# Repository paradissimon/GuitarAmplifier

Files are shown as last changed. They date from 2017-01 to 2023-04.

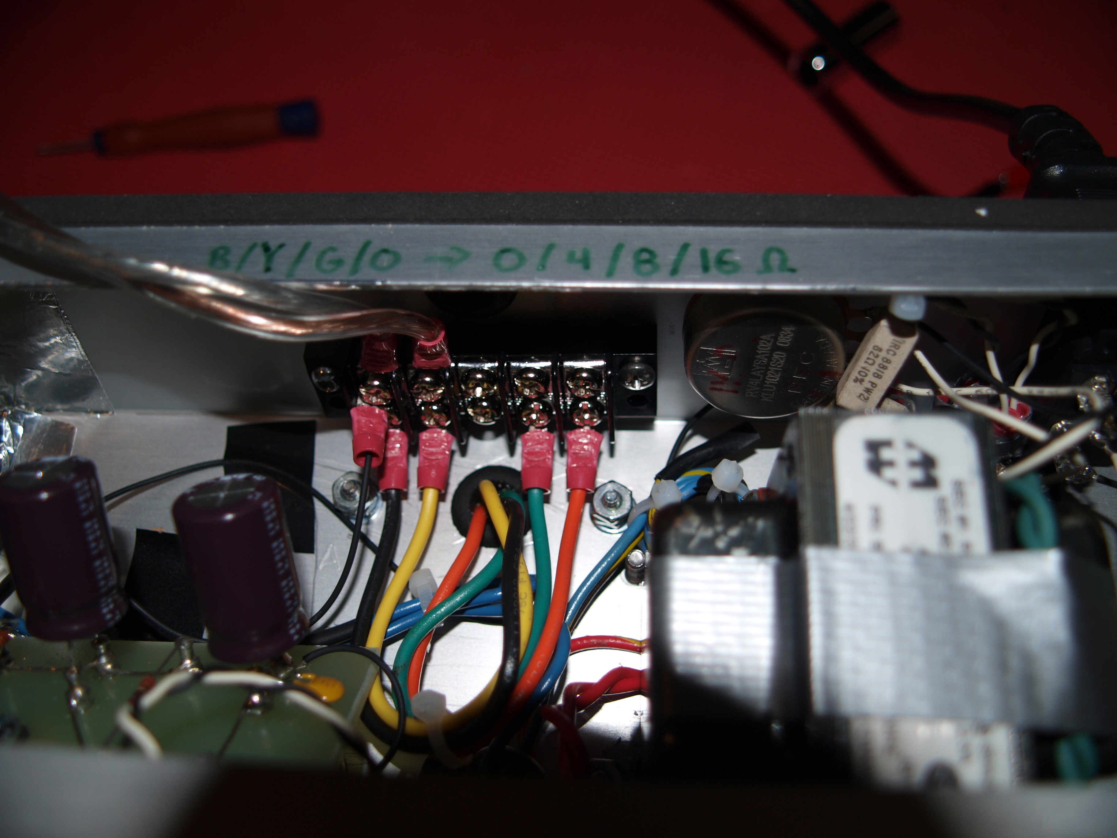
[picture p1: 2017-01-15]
Photos/A0154236.JPG

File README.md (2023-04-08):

All tube class A guitar amplifier
=========================

This is repository contains Autocad DXF layout and LTSpice schematics for a 5W class A guitar amplifier based on a **12AX7** preamplifier tube and **EL84** power tube.

The DXF layout in the Spice folder can be opened with the free QCad software which can be downloaded at http://www.qcad.org/en/qcad-downloads-trial

The schematic file works with Linear Technology's LTSpice electronic simulator available at http://www.linear.com/designtools/software/

The Photo folder contains some pictures of the actual build. I took the aluminium enclosure, cab and speaker out of an existing Line6 Spider III small guitar amplifier. The output transformer is a custom one salvaged from another amplifier. I guess any single-ended 5W/10W output transformer designed for EL84 tubes should be ok; mine has an input impedance of around 6000 ohms. The Line6 speaker is 4 ohms; use proper output tap for other speaker impedances.

Good books related to this project

* [Designing Power Supplies for Valve Amplifiers](https://www.amazon.ca/Designing-Power-Supplies-Valve-Amplifiers/dp/0956154514)

* [Designing Valve Preamps for Guitar and Bass](https://www.amazon.ca/Designing-Valve-Preamps-Guitar-Bass/dp/0956154506)

**Warning! This electronics project contains potentially lethal DC voltages of up to 300 volts.**

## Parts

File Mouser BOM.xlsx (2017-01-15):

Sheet: BOM
Description | # Manufacturier | # Mouser | Qté | Prix | Somme
100R | PR01000101000JR500 | 594-5073NW100R0J | 6 | 0.165 | 0.99 |  | 201.718
120R | PR01000101200JR500 | 594-5073NW120R0J | 6 | 0.165 | 0.99
150R | PR01000101500JR500 | 594-5073NW150R0J | 6 | 0.165 | 0.99
180R | PR01000101800JR500 | 594-5073NW180R0J | 6 | 0.165 | 0.99
220R | PR01000102200JR500 | 594-5073NW220R0J | 6 | 0.165 | 0.99
270R | PR01000102700JR500 | 594-5073NW270R0J | 6 | 0.165 | 0.99
330R | PR01000103300JR500 | 594-5073NW330R0J | 6 | 0.165 | 0.99
390R | PR01000103900JR500 | 594-5073NW390R0J | 6 | 0.165 | 0.99
470R | PR01000104700JR500 | 594-5073NW470R0J | 6 | 0.165 | 0.99
560R | PR01000105600JR500 | 594-5073NW560R0J | 6 | 0.165 | 0.99
680R | PR01000106800JR500 | 594-5073NW680R0J | 6 | 0.165 | 0.99
820R | PR01000108200JR500 | 594-5073NW820R0J | 6 | 0.165 | 0.99
1,0k | PR01000101001JR500 | 594-5073NW1K000J | 6 | 0.165 | 0.99
1,2k | PR01000101201JR500 | 594-5073NW1K200J | 6 | 0.165 | 0.99
1,5k | PR01000101501JR500 | 594-5073NW1K500J | 6 | 0.165 | 0.99
1,8k | PR01000101801JR500 | 594-5073NW1K800J | 6 | 0.165 | 0.99
2,2k | PR01000102201JR500 | 594-5073NW2K200J | 6 | 0.165 | 0.99
2,7k | PR01000102701JR500 | 594-5073NW2K700J | 6 | 0.165 | 0.99
3,3k | PR01000103301JR500 | 594-5073NW3K300J | 6 | 0.165 | 0.99
3,9k | PR01000103901JR500 | 594-5073NW3K900J | 6 | 0.165 | 0.99
4,7k | PR01000104701JR500 | 594-5073NW4K700J | 6 | 0.165 | 0.99
5,6k | PR01000105601JR500 | 594-5073NW5K600J | 6 | 0.165 | 0.99
6,8k | PR01000106801JR500 | 594-5073NW6K800J | 6 | 0.165 | 0.99
8,2k | PR01000108201JR500 | 594-5073NW8K200J | 6 | 0.165 | 0.99
10k | PR01000101002JR500 | 594-5073NW10K00J | 6 | 0.165 | 0.99
12k | PR01000101202JR500 | 594-5073NW12K00J | 6 | 0.165 | 0.99
15k | PR01000101502JR500 | 594-5073NW15K00J | 6 | 0.165 | 0.99
18k | PR01000101802JR500 | 594-5073NW18K00J | 6 | 0.165 | 0.99
22k | PR01000102202JR500 | 594-5073NW22K00J | 6 | 0.165 | 0.99
27k | PR01000102702JR500 | 594-5073NW27K00J | 6 | 0.165 | 0.99
33k | PR01000103302JR500 | 594-5073NW33K00J | 6 | 0.165 | 0.99
39k | PR01000103902JR500 | 594-5073NW39K00J | 6 | 0.165 | 0.99
47k | PR01000104702JR500 | 594-5073NW47K00J | 6 | 0.165 | 0.99
56k | PR01000105602JR500 | 594-5073NW56K00J | 6 | 0.165 | 0.99
68k | PR01000106802JR500 | 594-5073NW68K00J | 6 | 0.165 | 0.99
82k | PR01000108202JR500 | 594-5073NW82K00J | 6 | 0.165 | 0.99
100k | PR01000101003JR500 | 594-5073NW100K0J | 6 | 0.165 | 0.99
120k | PR01000101203JR500 | 594-5073NW120K0J | 6 | 0.165 | 0.99
150k | PR01000101503JR500 | 594-5073NW150K0J | 6 | 0.165 | 0.99
180k | PR01000101803JR500 | 594-5073NW180K0J | 6 | 0.165 | 0.99
220k | PR01000102203JR500 | 594-5073NW220K0J | 6 | 0.165 | 0.99
270k | PR01000102703JR500 | 594-5073NW270K0J | 6 | 0.165 | 0.99
330k | PR01000103303JR500 | 594-5073NW330K0J | 6 | 0.165 | 0.99
390k | PR01000103903JR500 | 594-5073NW390K0J | 6 | 0.165 | 0.99
470k | PR01000104703JR500 | 594-5073NW470K0J | 6 | 0.165 | 0.99
560k | PR01000105603JR500 | 594-5073NW560K0J | 6 | 0.165 | 0.99
680k | PR01000106803JR500 | 594-5073NW680K0J | 6 | 0.165 | 0.99
820k | PR01000108203JR500 | 594-5073NW820K0J | 6 | 0.165 | 0.99
1000k/2W | PR02000201004JR500 | 594-5083NW1M000J | 2 | 0.331 | 0.66
100R / 3W | PR03000201000JAC00 | 594-5093NW100R0J | 4 | 0.475 | 1.90
150R / 3W | PR03000201500JAC00 | 594-5093NW150R0J | 2 | 0.475 | 0.95
180R / 3W | PR03000201800JAC00 | 594-5093NW180R0J | 2 | 0.475 | 0.95
1k / 3W | PR03000201001JAC00 | 594-5093NW1K000J | 2 | 0.475 | 0.95
10k / 3W | PR03000201002JAC00 | 594-5093NW10K00J | 2 | 0.475 | 0.95
4R / 10W | 280-CR10-4.0-RC | 280-CR10-4.0-RC | 2 | 0.661 | 1.32 | Dummy load
UF4007 | UF4007 | 512-UF4007 | 10 | 0.341 | 3.41 | Diode rectification
10uF/50V | UST1C100MDD1TE | 647-UST1C100MDD1TE | 10 | 0.072 | 0.72 | Ref heater
100 uF/16V | UVR1C101MDD1TD | 647-UVR1C101MDD1TD | 10 | 0.052 | 0.52 | Cathode
47uF/350V | UPB2V470MHD | 647-UPB2V470MHD | 4 | 3.320 | 13.28 | Power
Power NPN BJT TO-220F | FJPF5027OTU | 512-FJPF5027OTU | 5 | 0.754 | 3.77
Small signal NPN BJT TO-92 | 2N5551BU | 512-2N5551BU | 50 | 0.039 | 1.95
Power MOSFET | IRF820PBF | 844-IRF820PBF | 5 | 1.210 | 6.05
Zener 12V 1N5242 | 1N5242B-TR | 78-1N5242B | 10 | 0.031 | 0.31 | Protection MOSFET
Ceramic cap 1000V 1nF | H102K25X7RN63J5R | 594-H102K25X7RN63J5R | 25 | 0.062 | 1.55 | Filtering
Film cap 0.0010uF (1.0nF 1000pF) 630V | 150102K630BB | 539-150102K630BB | 2 | 0.475 | 0.95 | Coupling
Film cap 0.0022uF (2.2 nF 2200pF) 630V | 150222J630BB | 539-150222J630BB | 2 | 0.620 | 1.24
Film cap 0.0033uF (3.3 nF 3300pF) 630V | 150332J630BB | 539-150332J630BB | 2 | 0.589 | 1.18
Film cap 0.0047uF (4.7 nF 4700pF) 630V | 150472K630BB | 539-150472K630BB | 2 | 0.527 | 1.05
Film cap 1uF 63V | 150105K63EC | 539-150105K63EC | 1 | 1.020 | 1.02 | Cathode 12ax7
Film cap 0.47uF 100V | 150474K100DC | 539-150474K100DC | 1 | 0.723 | 0.72
Terminal block 2pos | 1546306-2 | 571-15463062 | 1 | 0.527 | 0.53 | AC Mains
Terminal block 3pos | 1546306-3 | 571-15463063 | 2 | 1.000 | 2.00 | Heaters / High voltage
Terminal block 5pos | 1546306-5 | 571-15463065 | 1 | 1.680 | 1.68 | O.T. outputs
Ring terminal 22/20/18 AWG | 19070-0040 | 538-19070-0040 | 35 | 0.196 | 6.86 | Mounts for terminal block
TO220 Insulation kit | 4880SG | 532-4880SG | 2 | 2.100 | 4.20 | Insulation for heatsink
TO220 Heatsink | 577102B04000G | 532-577102B04000G | 2 | 0.393 | 0.79
Wire - Single Conductor 22AWG 7/30 MPPE 100' SPOOL WHITE | 6713 WH005 | 602-6713-100-01 | 1 | 35.850 | 35.85
Wire - Single Conductor 22AWG 7/30 MPPE 100' SPOOL BLACK | 6713 BK005 | 602-6713-100-02 | 1 | 35.850 | 35.85
6.3VAC 3A C.T. Transfor | F16X | 553-F16X | 1 | 12.920 | 12.92
Amber Neon 120V pilot 5/16 hole | 4700A3 | 606-4700A3 | 1 | 1.970 | 1.97
Switch DPST 120V | M2021BB1W01-RO | 633-M2021BB1W01-RO | 1 | 6.150 | 6.15 | Power switch
Order Number: 4468978 (https://ca.mouser.com/OrderHistory/OrderDetail.aspx?qs=9C%2fvjDbyW3X3ZtPHvCQXQaqbB6VQC2yj)

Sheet: Feuil1
 | 594-5073NW100R0J (http://ca.mouser.com/ProductDetail/Vishay-BC-Components/PR01000101000JR500/) | PR01000101000JR500 (http://ca.mouser.com/ProductDetail/Vishay-BC-Components/PR01000101000JR500/) | Vishay/BC Components (http://ca.mouser.com/bccomponents) | Metal Film Resistors - Through Hole 1watt 100ohms 5% PR01 100 5% | Page 727 (http://ca.mouser.com/catalog/catalogCAD/644/727.pdf) | 22.423 | Cut Tape |  |  |  | Details (http://ca.mouser.com/Search/include/RoHSCompliant.aspx?qs=PHIAxeuBAWmYLw3lUtLutA%3d%3d) | 100 Ohms | 5% | 1 Watt | 5073
Enlarge (http://ca.mouser.com/Vishay-BC-Components/Passive-Components/Resistors/Film-Resistors/Metal-Film-Resistors-Through-Hole/_/N-7gz41Z1z13zyf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) |  |  |  |  |  | In Stock | 1:00:00 | $0.165
 |  |  |  |  | Data Sheet |  | 100:00:00 | $0.083 | Min.: | 1
 |  |  |  |  |  |  | 500:00:00 | $0.072 | Mult.: | 1
 |  |  |  |  |  |  | 1,000: | $0.062 | Reel: | 5
 |  |  |  |  |  |  | Reel
 |  |  |  |  |  |  | 5,000: | $0.052
 |  |  |  |  |  |  | 10,000: | View (http://ca.mouser.com/ProductDetail/Vishay-BC-Components/PR01000101000JR500/)
 | 594-5073NW120R0J (http://ca.mouser.com/ProductDetail/Vishay-BC-Components/PR01000101200JR500/) | PR01000101200JR500 (http://ca.mouser.com/ProductDetail/Vishay-BC-Components/PR01000101200JR500/) | Vishay/BC Components (http://ca.mouser.com/bccomponents) | Metal Film Resistors - Through Hole 1watt 120ohms 5% | Page 727 (http://ca.mouser.com/catalog/catalogCAD/644/727.pdf) | 8.745 | Cut Tape |  |  |  | Details (http://ca.mouser.com/Search/include/RoHSCompliant.aspx?qs=PHIAxeuBAWmwXJoypx%252bQGg%3d%3d) | 120 Ohms | 5% | 1 Watt | 5073
Enlarge (http://ca.mouser.com/Vishay-BC-Components/Passive-Components/Resistors/Film-Resistors/Metal-Film-Resistors-Through-Hole/_/N-7gz41Z1z13zyf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) |  |  |  |  |  | In Stock | 1:00:00 | $0.165
 |  |  |  |  | Data Sheet |  | 100:00:00 | $0.083 | Min.: | 1
 |  |  |  |  |  |  | 500:00:00 | $0.072 | Mult.: | 1
 |  |  |  |  |  |  | 1,000: | $0.062 | Reel: | 5
 |  |  |  |  |  |  | Reel
 |  |  |  |  |  |  | 5,000: | $0.052
 |  |  |  |  |  |  | 10,000: | View (http://ca.mouser.com/ProductDetail/Vishay-BC-Components/PR01000101200JR500/)
 | 594-5073NW150R0J (http://ca.mouser.com/ProductDetail/Vishay-BC-Components/PR01000101500JR500/) | PR01000101500JR500 (http://ca.mouser.com/ProductDetail/Vishay-BC-Components/PR01000101500JR500/) | Vishay/BC Components (http://ca.mouser.com/bccomponents) | Metal Film Resistors - Through Hole 1watt 150ohms 5% | Page 727 (http://ca.mouser.com/catalog/catalogCAD/644/727.pdf) | 3.365 | Cut Tape |  |  |  | Details (http://ca.mouser.com/Search/include/RoHSCompliant.aspx?qs=ludH%252bm4YNCMMAySMSlrFlA%3d%3d) | 150 Ohms | 5% | 1 Watt | 5073
Enlarge (http://ca.mouser.com/Vishay-BC-Components/Passive-Components/Resistors/Film-Resistors/Metal-Film-Resistors-Through-Hole/_/N-7gz41Z1z13zyf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) |  |  |  |  |  | In Stock | 1:00:00 | $0.165
 |  |  |  |  | Data Sheet |  | 100:00:00 | $0.083 | Min.: | 1
 |  |  |  |  |  |  | 500:00:00 | $0.072 | Mult.: | 1
 |  |  |  |  |  |  | 1,000: | $0.062 | Reel: | 5
 |  |  |  |  |  |  | Reel
 |  |  |  |  |  |  | 5,000: | $0.052
 |  |  |  |  |  |  | 10,000: | View (http://ca.mouser.com/ProductDetail/Vishay-BC-Components/PR01000101500JR500/)
 | 594-5073NW180R0J (http://ca.mouser.com/ProductDetail/Vishay-BC-Components/PR01000101800JR500/) | PR01000101800JR500 (http://ca.mouser.com/ProductDetail/Vishay-BC-Components/PR01000101800JR500/) | Vishay/BC Components (http://ca.mouser.com/bccomponents) | Metal Film Resistors - Through Hole 1watt 180ohms 5% | Page 727 (http://ca.mouser.com/catalog/catalogCAD/644/727.pdf) | 9.241 | Cut Tape |  |  |  | Details (http://ca.mouser.com/Search/include/RoHSCompliant.aspx?qs=YmUReEAocUl%252bDAZht9mY8A%3d%3d) | 180 Ohms | 5% | 1 Watt | 5073
Enlarge (http://ca.mouser.com/Vishay-BC-Components/Passive-Components/Resistors/Film-Resistors/Metal-Film-Resistors-Through-Hole/_/N-7gz41Z1z13zyf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) |  |  |  |  |  | In Stock | 1:00:00 | $0.165
 |  |  |  |  | Data Sheet |  | 100:00:00 | $0.083 | Min.: | 1
 |  |  |  |  |  |  | 500:00:00 | $0.072 | Mult.: | 1
 |  |  |  |  |  |  | 1,000: | $0.062 | Reel: | 5
 |  |  |  |  |  |  | Reel
 |  |  |  |  |  |  | 5,000: | $0.052
 |  |  |  |  |  |  | 10,000: | View (http://ca.mouser.com/ProductDetail/Vishay-BC-Components/PR01000101800JR500/)
 | 594-5073NW220R0J (http://ca.mouser.com/ProductDetail/Vishay-BC-Components/PR01000102200JR500/) | PR01000102200JR500 (http://ca.mouser.com/ProductDetail/Vishay-BC-Components/PR01000102200JR500/) | Vishay/BC Components (http://ca.mouser.com/bccomponents) | Metal Film Resistors - Through Hole 1watt 220ohms 5% | Page 727 (http://ca.mouser.com/catalog/catalogCAD/644/727.pdf) | 12.401 | Cut Tape |  |  |  | Details (http://ca.mouser.com/Search/include/RoHSCompliant.aspx?qs=MQFOFZiEXaSG%2fquX5pavNw%3d%3d) | 220 Ohms | 5% | 1 Watt | 5073
Enlarge (http://ca.mouser.com/Vishay-BC-Components/Passive-Components/Resistors/Film-Resistors/Metal-Film-Resistors-Through-Hole/_/N-7gz41Z1z13zyf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) |  |  |  |  |  | In Stock | 1:00:00 | $0.165
 |  |  |  |  | Data Sheet |  | 100:00:00 | $0.083 | Min.: | 1
 |  |  |  |  |  |  | 500:00:00 | $0.072 | Mult.: | 1
 |  |  |  |  |  |  | 1,000: | $0.062 | Reel: | 5
 |  |  |  |  |  |  | Reel
 |  |  |  |  |  |  | 5,000: | $0.052
 |  |  |  |  |  |  | 10,000: | View (http://ca.mouser.com/ProductDetail/Vishay-BC-Components/PR01000102200JR500/)
 | 594-5073NW270R0J (http://ca.mouser.com/ProductDetail/Vishay-BC-Components/PR01000102700JR500/) | PR01000102700JR500 (http://ca.mouser.com/ProductDetail/Vishay-BC-Components/PR01000102700JR500/) | Vishay/BC Components (http://ca.mouser.com/bccomponents) | Metal Film Resistors - Through Hole 1watt 270ohms 5% | Page 727 (http://ca.mouser.com/catalog/catalogCAD/644/727.pdf) | 7.003 | Cut Tape |  |  |  | Details (http://ca.mouser.com/Search/include/RoHSCompliant.aspx?qs=14uVlELD1UoBj7tWtgOd9g%3d%3d) | 270 Ohms | 5% | 1 Watt | 5073
Enlarge (http://ca.mouser.com/Vishay-BC-Components/Passive-Components/Resistors/Film-Resistors/Metal-Film-Resistors-Through-Hole/_/N-7gz41Z1z13zyf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) |  |  |  |  |  | In Stock | 1:00:00 | $0.165
 |  |  |  |  | Data Sheet |  | 100:00:00 | $0.083 | Min.: | 1
 |  |  |  |  |  |  | 500:00:00 | $0.072 | Mult.: | 1
 |  |  |  |  |  |  | 1,000: | $0.062 | Reel: | 5
 |  |  |  |  |  |  | Reel
 |  |  |  |  |  |  | 5,000: | $0.052
 |  |  |  |  |  |  | 10,000: | View (http://ca.mouser.com/ProductDetail/Vishay-BC-Components/PR01000102700JR500/)
 | 594-5073NW330R0J (http://ca.mouser.com/ProductDetail/Vishay-BC-Components/PR01000103300JR500/) | PR01000103300JR500 (http://ca.mouser.com/ProductDetail/Vishay-BC-Components/PR01000103300JR500/) | Vishay/BC Components (http://ca.mouser.com/bccomponents) | Metal Film Resistors - Through Hole 1watt 330ohms 5% | Page 727 (http://ca.mouser.com/catalog/catalogCAD/644/727.pdf) | 11.385 | Cut Tape |  |  |  | Details (http://ca.mouser.com/Search/include/RoHSCompliant.aspx?qs=ebpeZUi5yKl%2fG1VsOnD%2fZw%3d%3d) | 330 Ohms | 5% | 1 Watt | 5073
Enlarge (http://ca.mouser.com/Vishay-BC-Components/Passive-Components/Resistors/Film-Resistors/Metal-Film-Resistors-Through-Hole/_/N-7gz41Z1z13zyf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) |  |  |  |  |  | In Stock | 1:00:00 | $0.165
 |  |  |  |  | Data Sheet | More Info Available (http://ca.mouser.com/ProductDetail/Vishay-BC-Components/PR01000103300JR500/) | 100:00:00 | $0.083 | Min.: | 1
 |  |  |  |  |  |  | 500:00:00 | $0.072 | Mult.: | 1
 |  |  |  |  |  |  | 1,000: | $0.062 | Reel: | 5
 |  |  |  |  |  |  | Reel
 |  |  |  |  |  |  | 5,000: | $0.052
 |  |  |  |  |  |  | 10,000: | View (http://ca.mouser.com/ProductDetail/Vishay-BC-Components/PR01000103300JR500/)
 | 594-5073NW390R0J (http://ca.mouser.com/ProductDetail/Vishay-BC-Components/PR01000103900JR500/) | PR01000103900JR500 (http://ca.mouser.com/ProductDetail/Vishay-BC-Components/PR01000103900JR500/) | Vishay/BC Components (http://ca.mouser.com/bccomponents) | Metal Film Resistors - Through Hole 1watt 390ohms 5% | Page 727 (http://ca.mouser.com/catalog/catalogCAD/644/727.pdf) | 8.192 | Cut Tape |  |  |  | Details (http://ca.mouser.com/Search/include/RoHSCompliant.aspx?qs=PHIAxeuBAWklVInDMciCUA%3d%3d) | 390 Ohms | 5% | 1 Watt | 5073
Enlarge (http://ca.mouser.com/Vishay-BC-Components/Passive-Components/Resistors/Film-Resistors/Metal-Film-Resistors-Through-Hole/_/N-7gz41Z1z13zyf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) |  |  |  |  |  | In Stock | 1:00:00 | $0.165
 |  |  |  |  | Data Sheet |  | 100:00:00 | $0.083 | Min.: | 1
 |  |  |  |  |  |  | 500:00:00 | $0.072 | Mult.: | 1
 |  |  |  |  |  |  | 1,000: | $0.062 | Reel: | 5
 |  |  |  |  |  |  | Reel
 |  |  |  |  |  |  | 5,000: | $0.052
 |  |  |  |  |  |  | 10,000: | View (http://ca.mouser.com/ProductDetail/Vishay-BC-Components/PR01000103900JR500/)
 | 594-5073NW470R0J (http://ca.mouser.com/ProductDetail/Vishay-BC-Components/PR01000104700JR500/) | PR01000104700JR500 (http://ca.mouser.com/ProductDetail/Vishay-BC-Components/PR01000104700JR500/) | Vishay/BC Components (http://ca.mouser.com/bccomponents) | Metal Film Resistors - Through Hole 1watt 470ohms 5% | Page 727 (http://ca.mouser.com/catalog/catalogCAD/644/727.pdf) | 16.38 | Cut Tape |  |  |  | Details (http://ca.mouser.com/Search/include/RoHSCompliant.aspx?qs=ChQ8krfRUi61iVVrFGp3Pg%3d%3d) | 470 Ohms | 5% | 1 Watt | PR01
Enlarge (http://ca.mouser.com/Vishay-BC-Components/Passive-Components/Resistors/Film-Resistors/Metal-Film-Resistors-Through-Hole/_/N-7gz41Z1z13zyf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) |  |  |  |  |  | In Stock | 1:00:00 | $0.165
 |  |  |  |  | Data Sheet |  | 100:00:00 | $0.083 | Min.: | 1
 |  |  |  |  |  |  | 500:00:00 | $0.072 | Mult.: | 1
 |  |  |  |  |  |  | 1,000: | $0.062 | Reel: | 5
 |  |  |  |  |  |  | Reel
 |  |  |  |  |  |  | 5,000: | $0.052
 |  |  |  |  |  |  | 10,000: | View (http://ca.mouser.com/ProductDetail/Vishay-BC-Components/PR01000104700JR500/)
 | 594-5073NW560R0J (http://ca.mouser.com/ProductDetail/Vishay-BC-Components/PR01000105600JR500/) | PR01000105600JR500 (http://ca.mouser.com/ProductDetail/Vishay-BC-Components/PR01000105600JR500/) | Vishay/BC Components (http://ca.mouser.com/bccomponents) | Metal Film Resistors - Through Hole 1watt 560ohms 5% | Page 727 (http://ca.mouser.com/catalog/catalogCAD/644/727.pdf) | 7.882 | Cut Tape |  |  |  | Details (http://ca.mouser.com/Search/include/RoHSCompliant.aspx?qs=Zec1518NjxB0xdYBqc311Q%3d%3d) | 560 Ohms | 5% | 1 Watt | 5073
Enlarge (http://ca.mouser.com/Vishay-BC-Components/Passive-Components/Resistors/Film-Resistors/Metal-Film-Resistors-Through-Hole/_/N-7gz41Z1z13zyf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) |  |  |  |  |  | In Stock | 1:00:00 | $0.165
 |  |  |  |  | Data Sheet |  | 100:00:00 | $0.083 | Min.: | 1
 |  |  |  |  |  |  | 500:00:00 | $0.072 | Mult.: | 1
 |  |  |  |  |  |  | 1,000: | $0.062 | Reel: | 5
 |  |  |  |  |  |  | Reel
 |  |  |  |  |  |  | 5,000: | $0.052
 |  |  |  |  |  |  | 10,000: | View (http://ca.mouser.com/ProductDetail/Vishay-BC-Components/PR01000105600JR500/)
 | 594-5073NW680R0J (http://ca.mouser.com/ProductDetail/Vishay-BC-Components/PR01000106800JR500/) | PR01000106800JR500 (http://ca.mouser.com/ProductDetail/Vishay-BC-Components/PR01000106800JR500/) | Vishay/BC Components (http://ca.mouser.com/bccomponents) | Metal Film Resistors - Through Hole 1watt 680ohms 5% | Page 727 (http://ca.mouser.com/catalog/catalogCAD/644/727.pdf) | 6.624 | Cut Tape |  |  |  | Details (http://ca.mouser.com/Search/include/RoHSCompliant.aspx?qs=ludH%252bm4YNCNk6ULJYj2wlw%3d%3d) | 680 Ohms | 5% | 1 Watt | 5073
Enlarge (http://ca.mouser.com/Vishay-BC-Components/Passive-Components/Resistors/Film-Resistors/Metal-Film-Resistors-Through-Hole/_/N-7gz41Z1z13zyf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) |  |  |  |  |  | In Stock | 1:00:00 | $0.165
 |  |  |  |  | Data Sheet |  | 100:00:00 | $0.083 | Min.: | 1
 |  |  |  |  |  |  | 500:00:00 | $0.072 | Mult.: | 1
 |  |  |  |  |  |  | 1,000: | $0.062 | Reel: | 5
 |  |  |  |  |  |  | Reel
 |  |  |  |  |  |  | 5,000: | $0.052
 |  |  |  |  |  |  | 10,000: | View (http://ca.mouser.com/ProductDetail/Vishay-BC-Components/PR01000106800JR500/)
 | 594-5073NW820R0J (http://ca.mouser.com/ProductDetail/Vishay-BC-Components/PR01000108200JR500/) | PR01000108200JR500 (http://ca.mouser.com/ProductDetail/Vishay-BC-Components/PR01000108200JR500/) | Vishay/BC Components (http://ca.mouser.com/bccomponents) | Metal Film Resistors - Through Hole 1watt 820ohms 5% | Page 727 (http://ca.mouser.com/catalog/catalogCAD/644/727.pdf) | 5.778 | Cut Tape |  |  |  | Details (http://ca.mouser.com/Search/include/RoHSCompliant.aspx?qs=ludH%252bm4YNCP1VssKPNJtEw%3d%3d) | 820 Ohms | 5
Enlarge (http://ca.mouser.com/Vishay-BC-Components/Passive-Components/Resistors/Film-Resistors/Metal-Film-Resistors-Through-Hole/_/N-7gz41Z1z13zyf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) |  |  |  |  |  | In Stock | 1:00:00 | $0.165
 |  |  |  |  | Data Sheet |  | 100:00:00 | $0.083 | Min.: | 1
 |  |  |  |  |  |  | 500:00:00 | $0.072 | Mult.: | 1
 |  |  |  |  |  |  | 1,000: | $0.062 | Reel: | 5
 |  |  |  |  |  |  | Reel
 |  |  |  |  |  |  | 5,000: | $0.052
 |  |  |  |  |  |  | 10,000: | View (http://ca.mouser.com/ProductDetail/Vishay-BC-Components/PR01000108200JR500/)

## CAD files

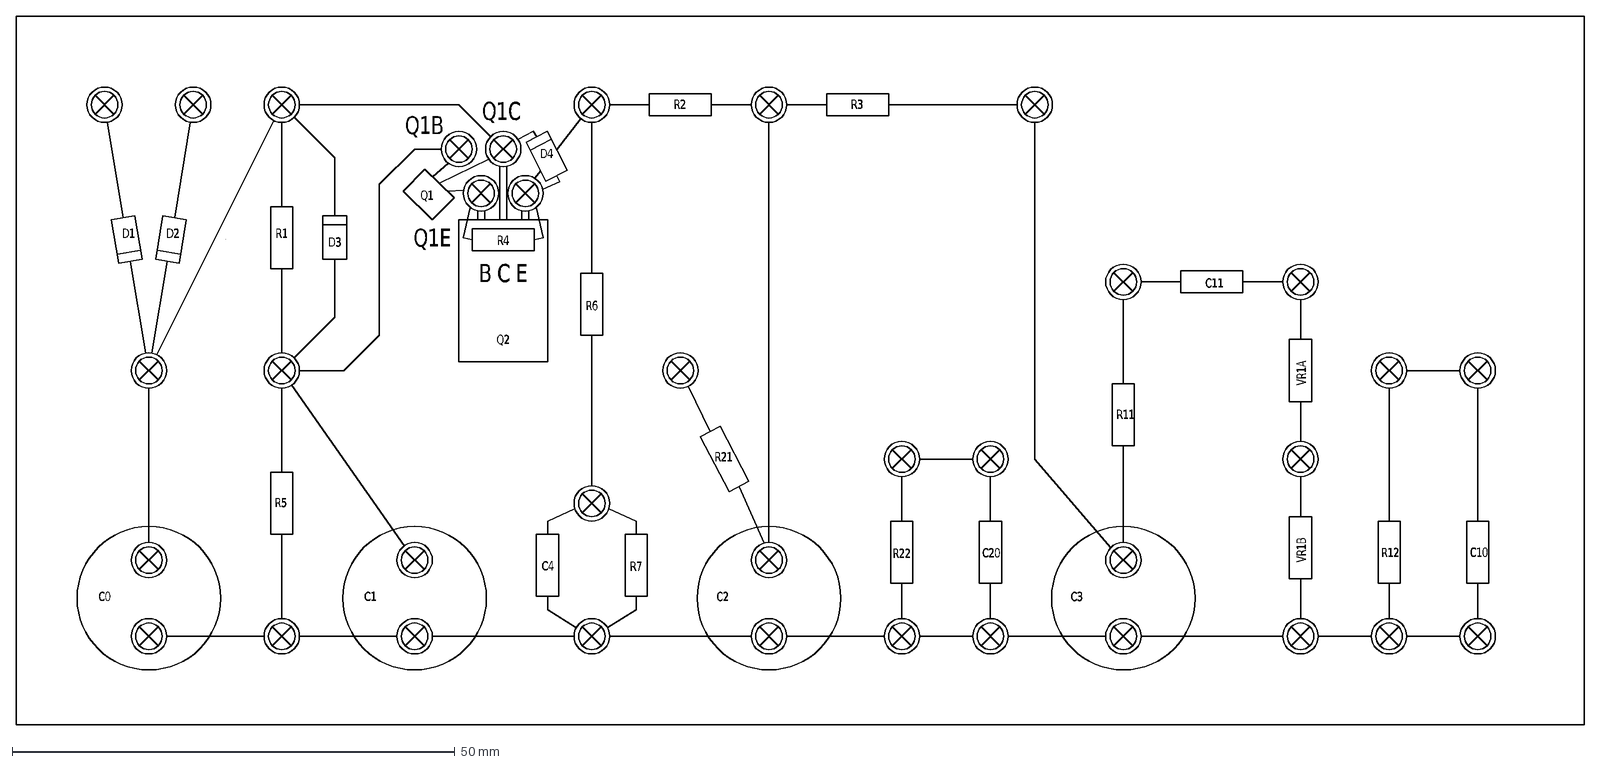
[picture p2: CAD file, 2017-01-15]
Plan/Layout.dxf
D1
D2
D3
R1
R5
C0
C1
Q2
R4
D4
Q1E
Q1B
Q1C
B C E
Q1
R6
C4
R7
C2
R2
R3
R21
C3
R22
C20
R11
VR1A
VR1B
C11
R12
C10

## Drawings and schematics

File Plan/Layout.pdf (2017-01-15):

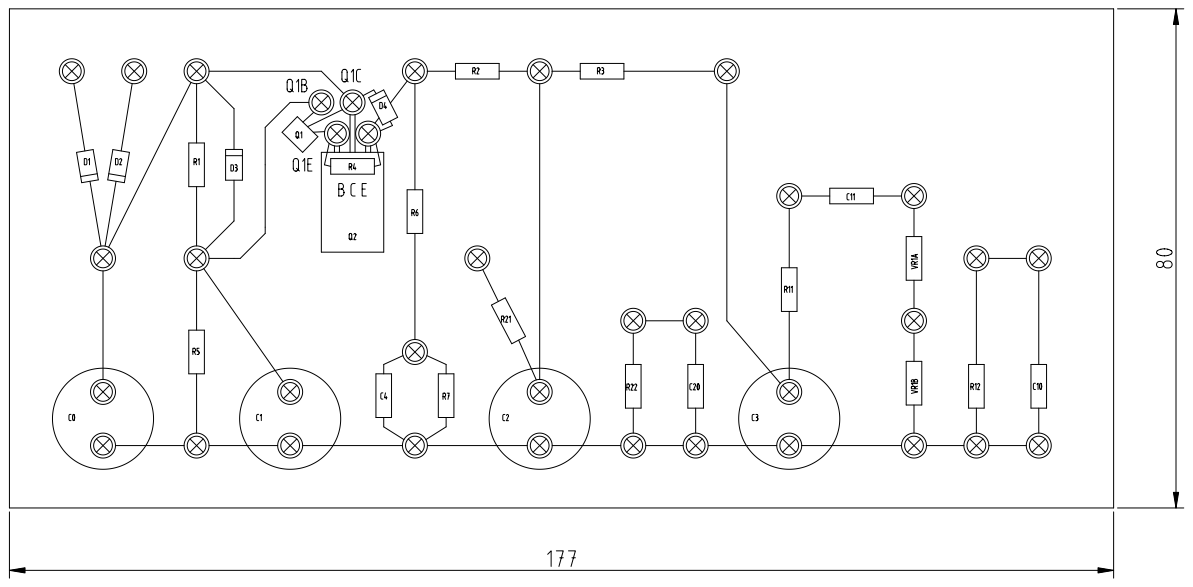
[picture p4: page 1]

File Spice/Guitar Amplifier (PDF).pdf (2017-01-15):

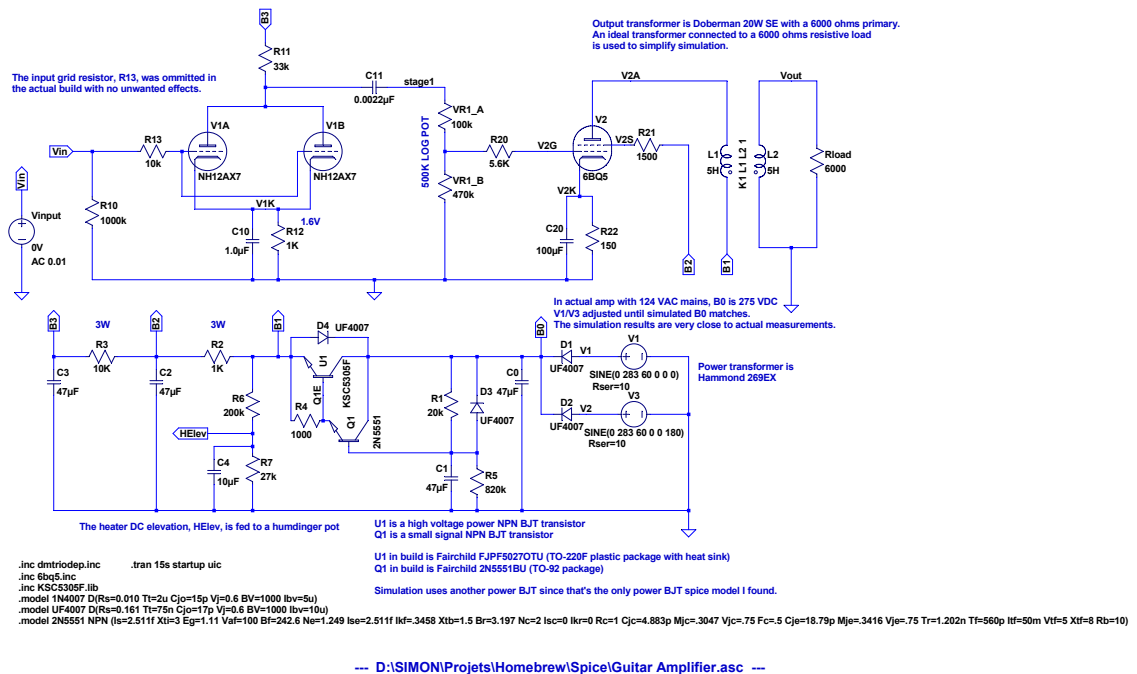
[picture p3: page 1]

Output transformer is Doberman 20W SE with a 6000 ohms primary.
An ideal transformer connected to a 6000 ohms resistive load
is used to simplify simulation.

The input grid resistor, R13, was ommitted in
the actual build with no unwanted effects.

In actual amp with 124 VAC mains, B0 is 275 VDC
V1/V3 adjusted until simulated B0 matches.
The simulation results are very close to actual measurements.

The heater DC elevation, HElev, is fed to a humdinger pot

U1 is a high voltage power NPN BJT transistor
Q1 is a small signal NPN BJT transistor

U1 in build is Fairchild FJPF5027OTU (TO-220F plastic package with heat sink)
Q1 in build is Fairchild 2N5551BU (TO-92 package)

.inc 6bq5.inc
.inc KSC5305F.lib
.model 1N4007 D(Rs=0.010 Tt=2u Cjo=15p Vj=0.6 BV=1000 Ibv=5u)
.model UF4007 D(Rs=0.161 Tt=75n Cjo=17p Vj=0.6 BV=1000 Ibv=10u)

Simulation uses another power BJT since that's the only power BJT spice model I found.

--- D:\SIMON\Projets\Homebrew\Spice\Guitar Amplifier.asc ---
